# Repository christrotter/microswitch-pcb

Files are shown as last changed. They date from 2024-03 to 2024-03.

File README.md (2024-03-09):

# microswitch-pcb
Designed for use on the [ArcPedals mk2](https://github.com/christrotter/qmk_firmware/tree/arcboard-series/keyboards/handwired/arcpedals_mk2) - with the accompanying files, a drop-in replacement for the old MX-based switches.

JLC wanted to charge me extra for using SK6812-MINI-E leds, so I swapped over to the SK6805 and tripled the led count.  As one does.

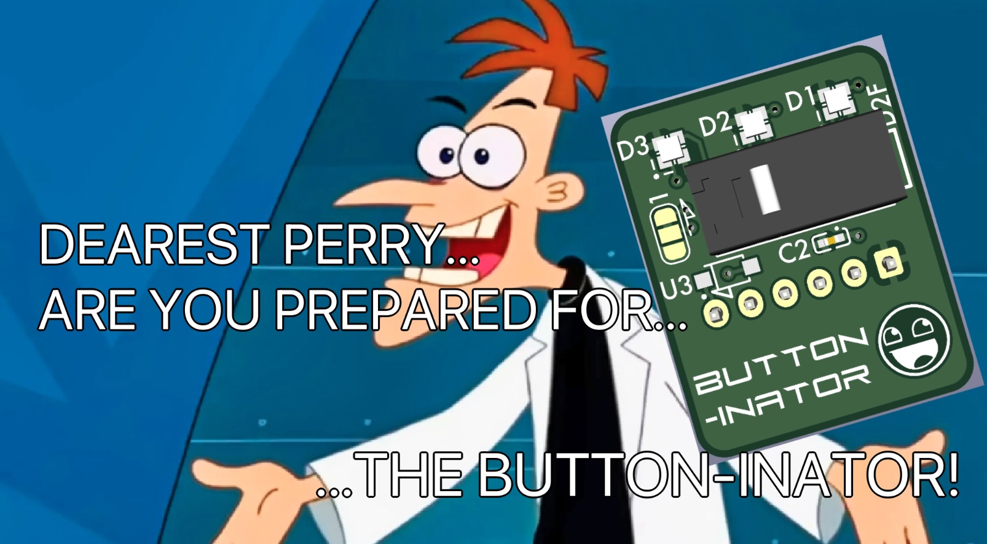
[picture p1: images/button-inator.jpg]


# Overview
Only items of note - the pour is on the top layer only, and I tried to make it as friendly for manufacturing and human usage as possible.

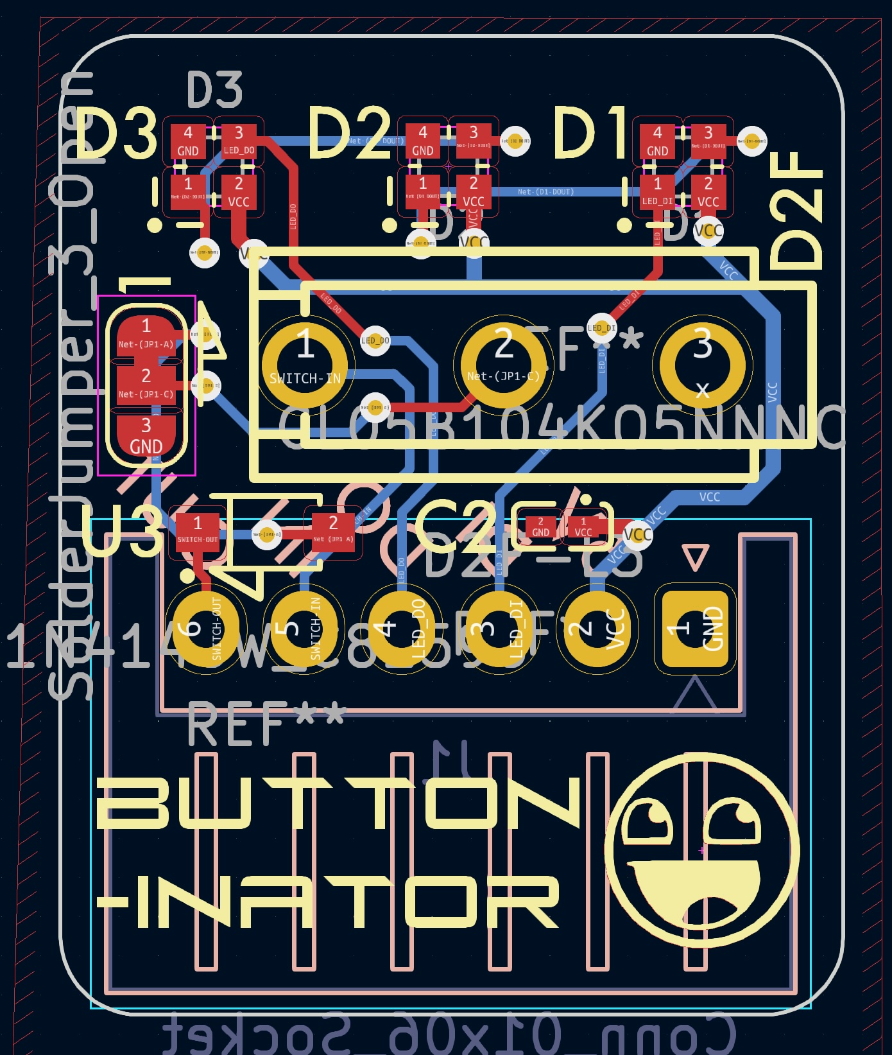
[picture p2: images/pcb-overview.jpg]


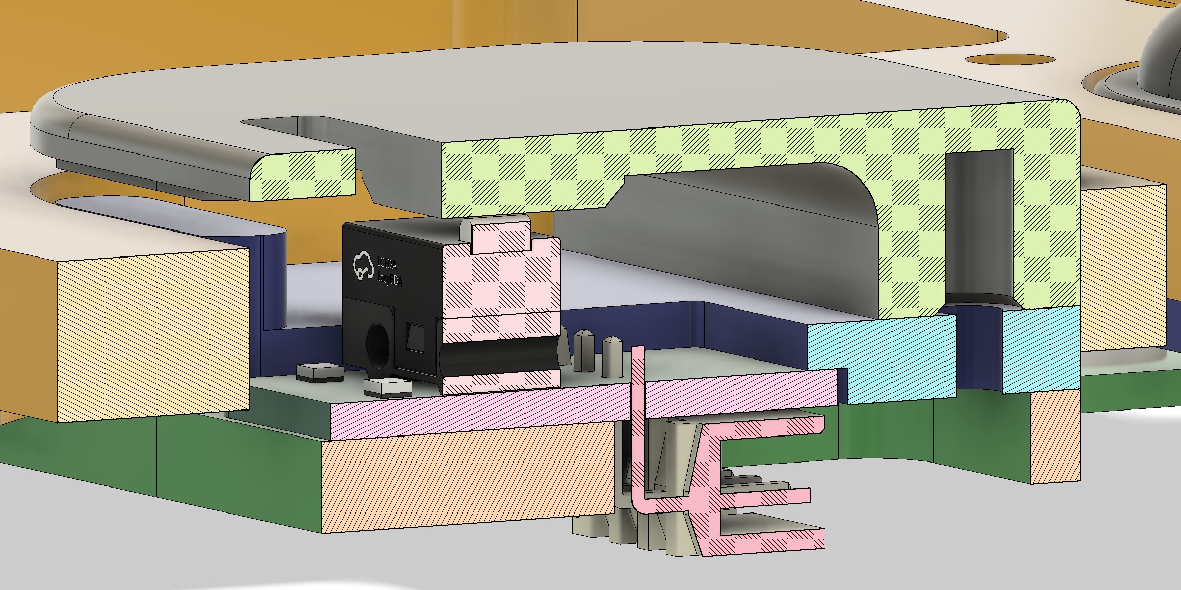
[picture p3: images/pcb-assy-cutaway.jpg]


## Parts
Gerbers, bom, position files and more in the releases section.

- 0402 100nF multilayer ceramic capacitor
- SOD-123F 1N4148W diode
- Omron D2F-L microswitch (key point, plunger only; heavier spring cuz feet)
- JST-XH-2.54 horizontal (or vertical, up to you) 6-pin connector
- 3x SK6805-EC15 LEDs

# Schematic overview
Pretty straightforward.
- 2.54 header (I designed for JST-XH 2.54 horizontal)
- 5v/GND power system w. 100nF capacitor
- LED signal via DI/DO pins
- 'key' signal via IN/OUT pins w. default diode on return leg
  - optionally cut the 2/3 bridge trace and solder pads 1/2 together for the direct pin (to GND)

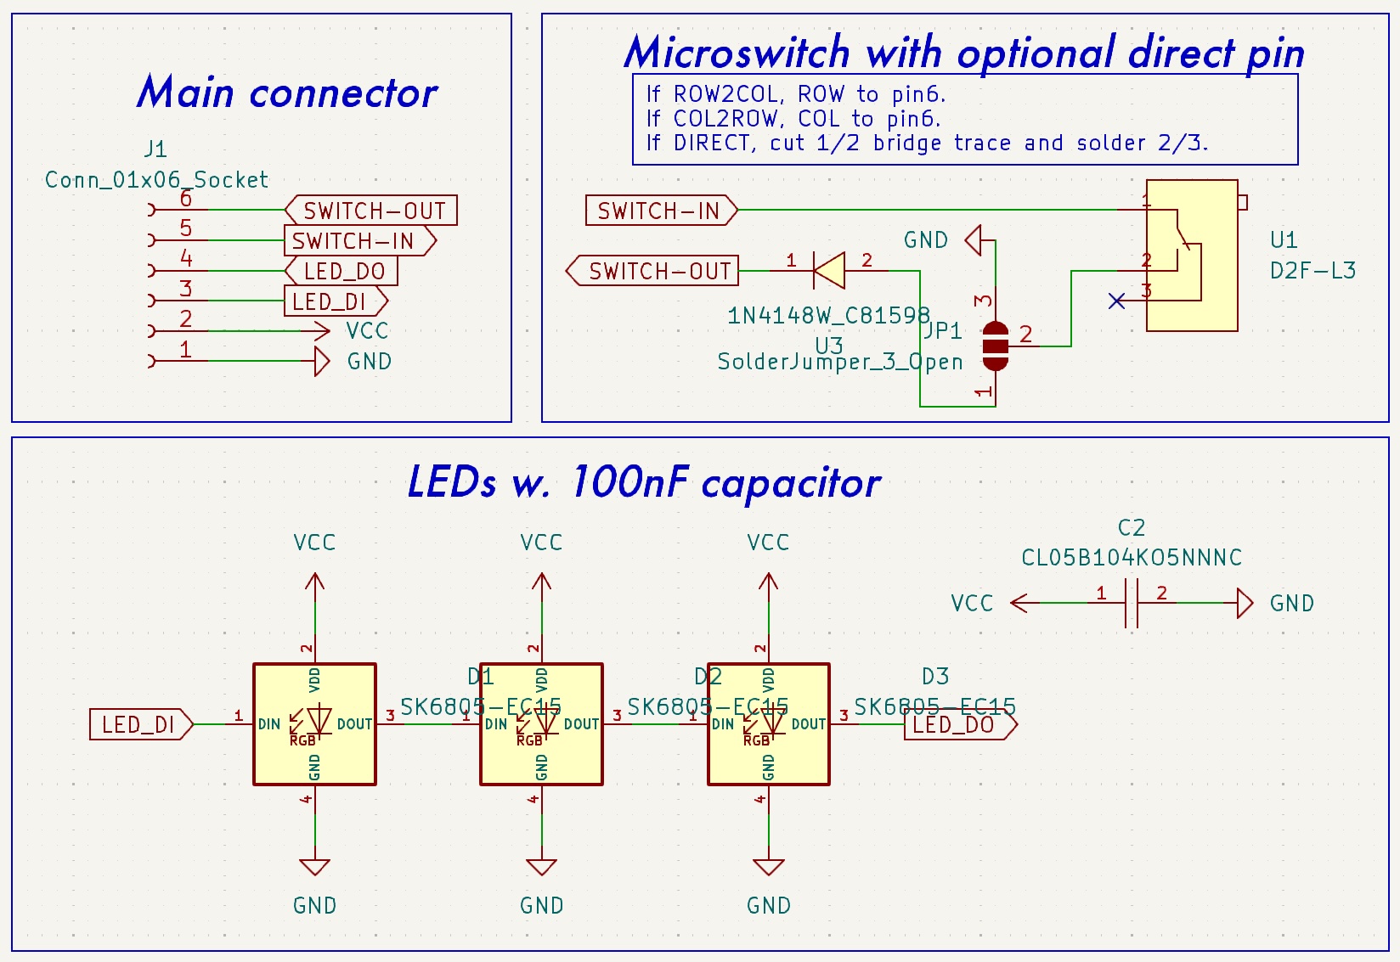
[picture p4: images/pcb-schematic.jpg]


# 3d view
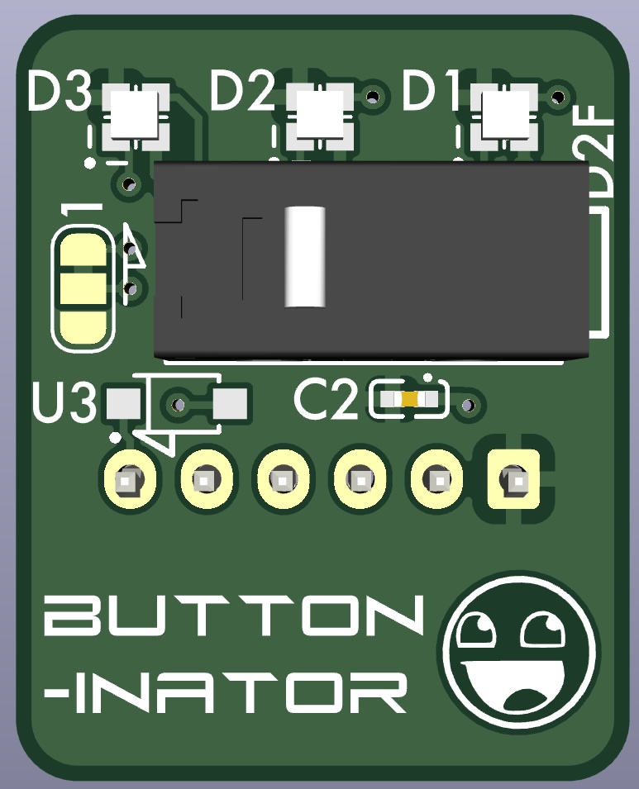
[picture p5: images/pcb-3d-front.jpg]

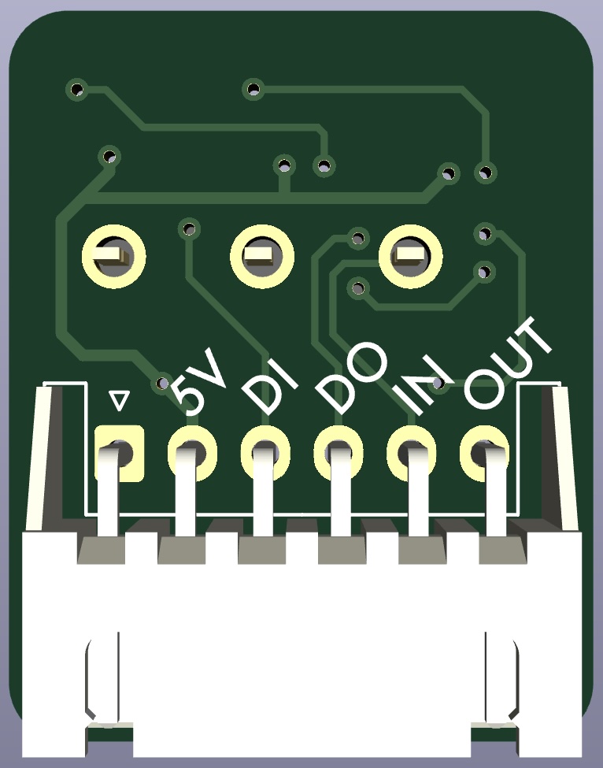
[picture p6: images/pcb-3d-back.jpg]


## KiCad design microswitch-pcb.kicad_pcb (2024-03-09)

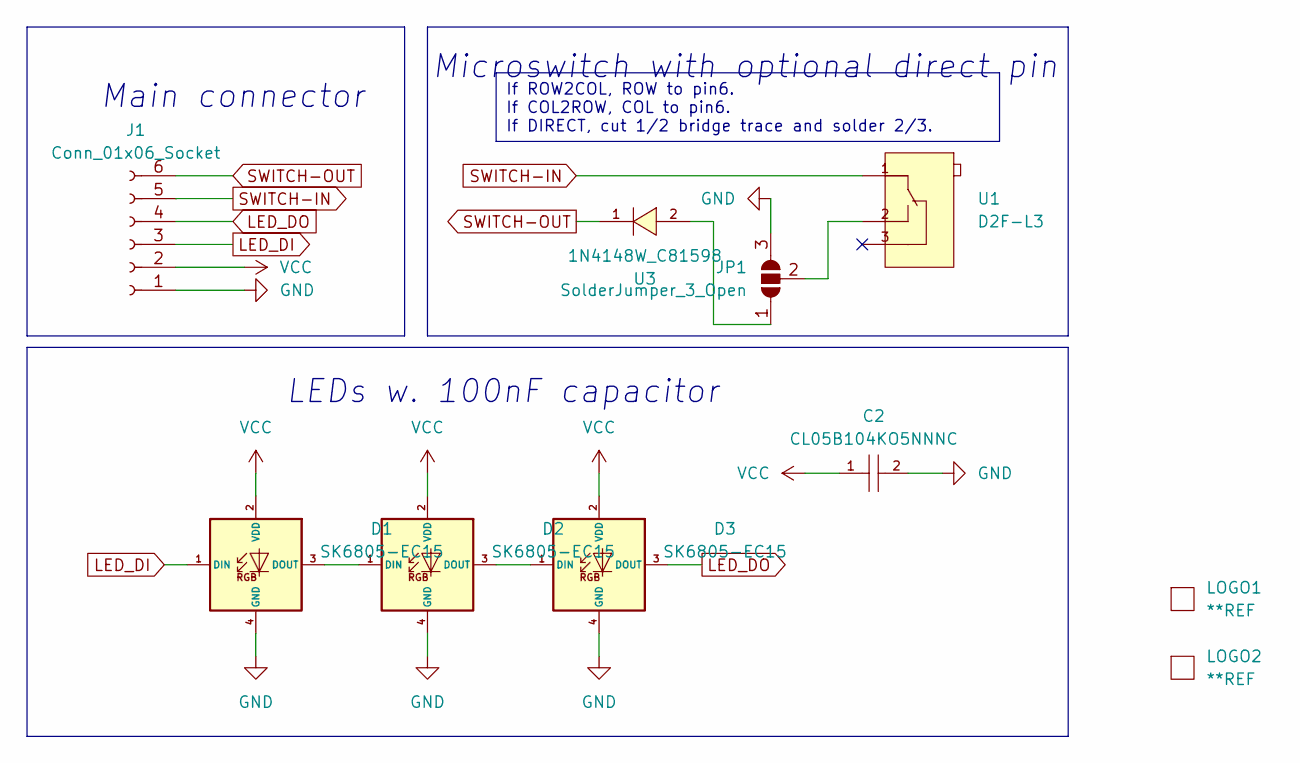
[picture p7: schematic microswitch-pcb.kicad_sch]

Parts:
C2: CL05B104KO5NNNC; C0402; LCSC C1525
D1, D2, D3: SK6805-EC15; LED_dilemma_SK6805-EC15_1.5x1.5mm_P0.6mm_handsolder; MPN SK6805-EC15; LCSC C2890035
J1: Conn_01x06_Socket; JST_XH_S6B-XH-A_1x06_P2.50mm_Horizontal
JP1: SolderJumper_3_Open; SolderJumper-3_P1.3mm_Bridged12_RoundedPad1.0x1.5mm_NumberL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
LOGO1, LOGO2: **REF; awesome-logo
U1: D2F-L3; SW-TH_D2F-L; LCSC C469124
U3: 1N4148W_C81598; SOD-123F_L2.7-W1.6-LS3.8-RD; LCSC C81598

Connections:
GND: C2.2, D1.4 (GND), D2.4 (GND), D3.4 (GND), J1.1, JP1.3 (B)
LED_DI: D1.1 (DIN), J1.3
LED_DO: D3.3 (DOUT), J1.4
unnamed: D1.3 (DOUT), D2.1 (DIN)
unnamed: D2.3 (DOUT), D3.1 (DIN)
unnamed: JP1.1 (A), U3.2 (A)
unnamed: JP1.2 (C), U1.2 (NO)
SWITCH-IN: J1.5, U1.1 (COM)
SWITCH-OUT: J1.6, U3.1 (K)
VCC: C2.1, D1.2 (VDD), D2.2 (VDD), D3.2 (VDD), J1.2

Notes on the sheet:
If ROW2COL, ROW to pin6. If COL2ROW, COL to pin6. If DIRECT, cut 1/2 bridge trace and solder 2/3.
Main connector
Microswitch with optional direct pin
LEDs w. 100nF capacitor

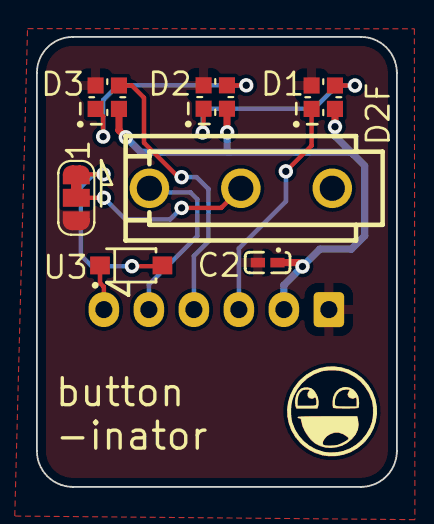
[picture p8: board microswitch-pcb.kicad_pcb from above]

Board: 2 copper layers, 20.0 x 25.0 mm, 10 parts (1 on the bottom side), 10 nets.

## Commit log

2024-03-09 order placed
    [microswitch-pcb.kicad_pcb, microswitch-pcb.kicad_sch]
2024-03-09 adding readme
    [microswitch-pcb.kicad_pcb, microswitch-pcb.kicad_sch]
